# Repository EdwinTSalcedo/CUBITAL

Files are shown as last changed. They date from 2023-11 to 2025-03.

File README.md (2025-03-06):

<h1 align="center">Edge AI-Based Vein Detector for Efficient Venipuncture in the Antecubital Fossa (CUBITAL)</h1> 

This repository contains supplementary material for the conference paper [*"Edge AI-Based Vein Detector for Efficient Venipuncture in the Antecubital Fossa"*](https://link.springer.com/chapter/10.1007/978-3-031-47640-2_24) (MICAI 2023 Oral session). **Authors:** [Edwin Salcedo](https://www.linkedin.com/in/edwinsalcedo) and [Patricia Peñaloza](https://www.linkedin.com/in/patricia-jael-pe%C3%B1aloza-sola-6b9b65131)

[[Project page]](https://edwinsalcedo.com/publication/cubital) [[Dataset]](https://drive.google.com/drive/folders/19DaK7T81qTxgBzirvBGdMyVUj8mOCcOx?usp=sharing) [[arXiv]](https://arxiv.org/pdf/2310.18234) 

<p align="center">

</p>

## Contents
[1. Overview](#overview) </br>
* [Motivation](#motivation) </br>
* [Computer vision system](#cvsystem) </br>
* [Hardware prototype](#hardwareprototype) </br>

[2. Dataset](#dataset) </br>
* [Data collection](#datacollection) </br>
* [Preliminary results](#preliminaryresults) </br>
* [Validation data](#validationdata) </br>

[3. Getting started](#gettingstarted) </br>
* [Initial inference samples](#initialinference) </br>
* [Graphical user interface (GUI)](#gui) </br>
* [On-device deployment](#deployment) </br>

[4. Citation](#citation) </br>
<br>

## 1. Overview

### Motivation
Assessing vein condition and visibility is crucial before obtaining intravenous access in the antecubital fossa, a common site for blood draws and intravenous therapy. However, medical practitioners often struggle with patients who have less visible veins due to factors such as fluid retention, age, obesity, darker skin tones, or diabetes. Current research explores the use of near-infrared (NIR) imaging and deep learning (DL) for forearm vein segmentation, achieving high precision. However, a research gap remains in the recognition of veins, specifically in the antecubital fossa. Additionally, most studies rely on stationary computers, limiting portability for medical personnel during venipuncture procedures. To address these challenges, we propose a portable vein finder for the antecubital fossa based on the Raspberry Pi 4B.

### Computer vision system
We implemented various vein semantic segmentation models in <a href="https://github.com/EdwinTSalcedo/CUBITAL/blob/master/notebooks/Deep_Learning_based_Vein_Segmentation.ipynb
">`Deep_Learning_based_Segmentation.ipynb`</a> and selected the best-performing one—a U-Net model. We then enhanced it in <a href="https://github.com/EdwinTSalcedo/CUBITAL/blob/master/notebooks/Inference_Multi_task_U_Net.ipynb">`Inference_Multi_task_U_Net.ipynb`</a> by adding an additional head to predict the coordinates of the antecubital fossa and its angle. The final computer vision system deployed in the vein finder is shown below:

<p align="center">
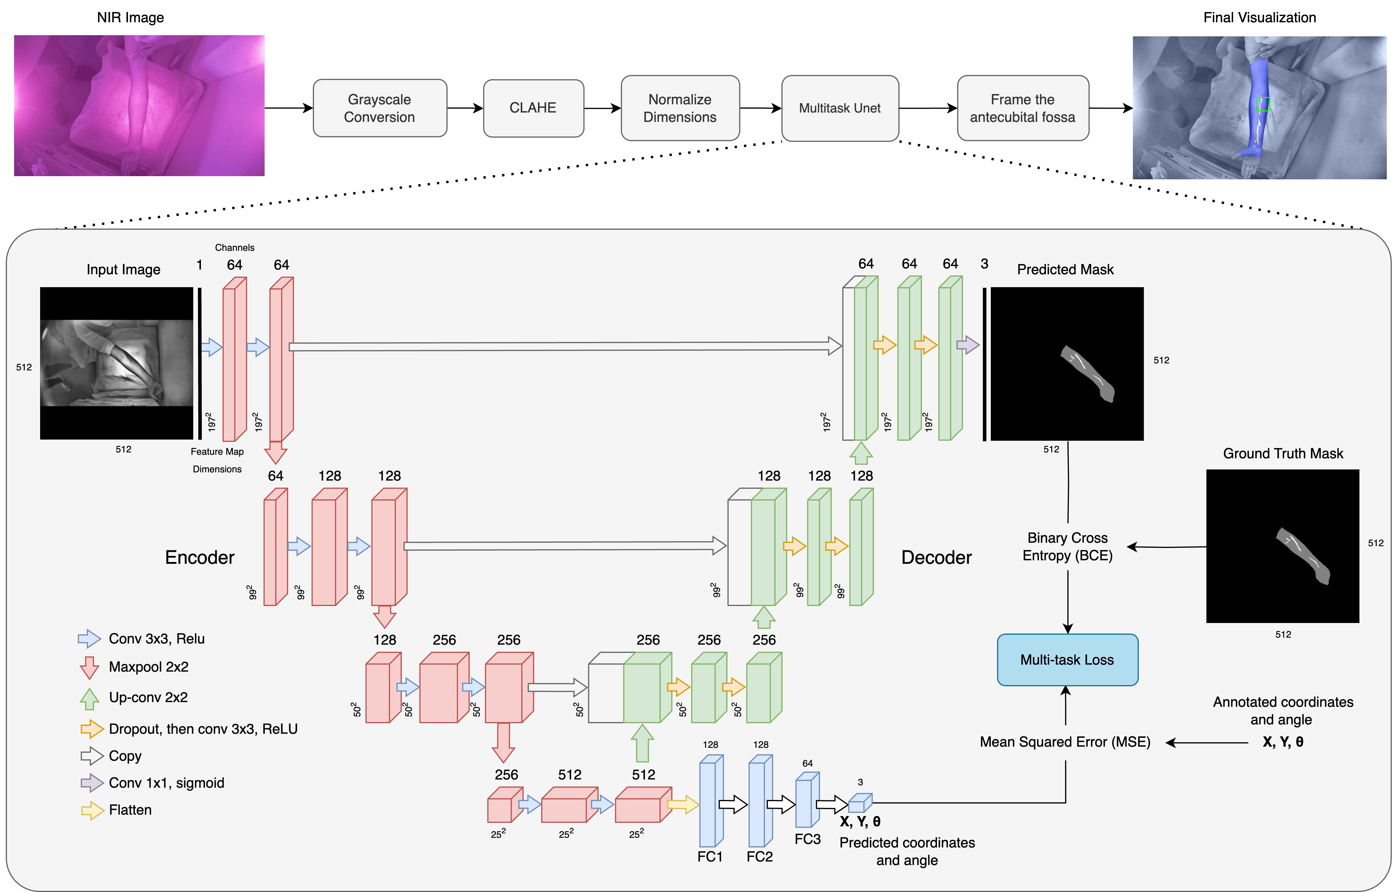
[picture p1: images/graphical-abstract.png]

</p>

We also include plots showing the model's layers in both <a href='https://github.com/EdwinTSalcedo/CUBITAL/blob/master/images/model_plot.png'>horizontal</a> and <a href='https://github.com/EdwinTSalcedo/CUBITAL/blob/master/images/model_plot.jpeg'>vertical</a> alignment.

### Hardware prototype

The device was designed using the 3D CAD software SolidWorks. It can be viewed by opening the file [`Ensamblaje.SLDASM`](cad/Ensamblaje.SLDASM). We also provide a detailed list of its components and visuals of the final 3D-printed prototype.

<p align="center">
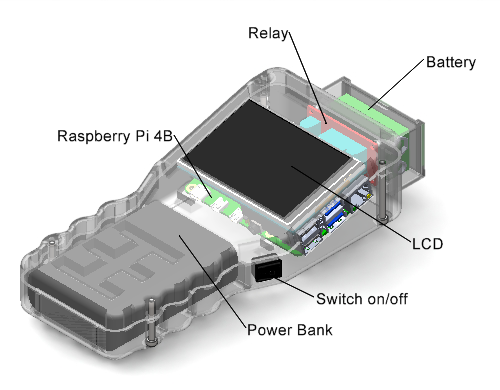
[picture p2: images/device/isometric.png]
  
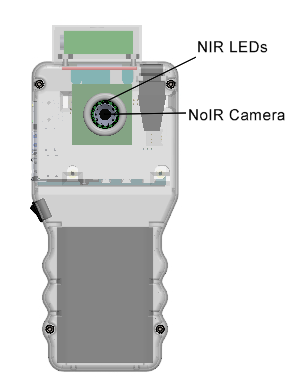
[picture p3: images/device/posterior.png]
  
</p>

| Component | Specifications |  CAD Design |
| --- | --- | --- |
| Power bank | <a href="https://www.amazon.com/Xiaomi-10000mAh-Portable-Charging-Delivery/dp/B08WCKLBJJ" target="_blank"> Xiaomi Mi Power Bank 3 </a> | [`Power bank`](cad/powerbank.SLDPRT) | 
| NIR Camera | <a href="https://www.raspberrypi.com/products/pi-noir-camera-v2/" target="_blank"> Raspberry Pi Camera Module 2 NoIR </a> | [`Holder`](cad/cam_holder.SLDPRT) [`Picam Noir`](cad/pi_cam.SLDPRT) [`Leds Matrix`](cad/leds_matrix.SLDPRT) |  
| LCD display | <a href="https://www.waveshare.com/3.5inch-rpi-lcd-b.htm" target="_blank"> Waveshare 3.5inch Touch Screen </a> | [`Screen`](cad/lcd_screen.SLDPRT) [`LCD Assembly`](cad/rpi_lcd.SLDPRT) |  
| Processing unit | <a href="https://www.raspberrypi.com/products/raspberry-pi-4-model-b/" target="_blank"> Raspberry Pi 4 Model B </a> | [`Raspberry Pi 4B`](cad/raspberryPi4B.SLDPRT) | 
| Relay module | <a href="https://www.amazon.com/Channel-Module-Trigger-Optocoupler-Arduino/dp/B079FJSYGY?th=1" target="_blank"> D.C. 5V 1 Channel Relay Module with Optocoupler </a> | [`Relay`](cad/relay_module.SLDPRT) |
| LED matrix | <a href="https://www.alibaba.com/product-detail/5x7cm-Placa-PCB-perforated_300011363294.html" target="_blank"> Perforated Phenolic Plate 5x7cm </a> + 12 <a href="https://www.amazon.com/Infrared-Lighting-Electronics-Components-Emitting/dp/B01BVGIZGC?th=1" target="_blank"> Infrared Ray IR 940nm Emitter LED Diode Lights </a> | [`LED Matrix`](cad/leds_matrix.SLDPRT) |
| On/off switch | <a href="https://www.amazon.com/KCD1-101-Perforate-19-13-Pin/dp/B0DCP5RSXF?th=1" target="_blank"> ON-OFF Switch 19*13mm KCD1-101 </a> | - |
| Case | - | [`Base`](cad/base.SLDPRT) [`Cover`](cad/cover.SLDPRT) [`Charger`](cad/charger.SLDPRT) |
| 9v battery holder | - | [`Case`](cad/battery_cover.SLDPRT) [`Holder`](cad/battery_holder.SLDPRT) [`Battery`](cad/battery.SLDPRT) | 
 
|  Frontal view |  Back view | Side view | Inner view |  
|---|---|---|---|
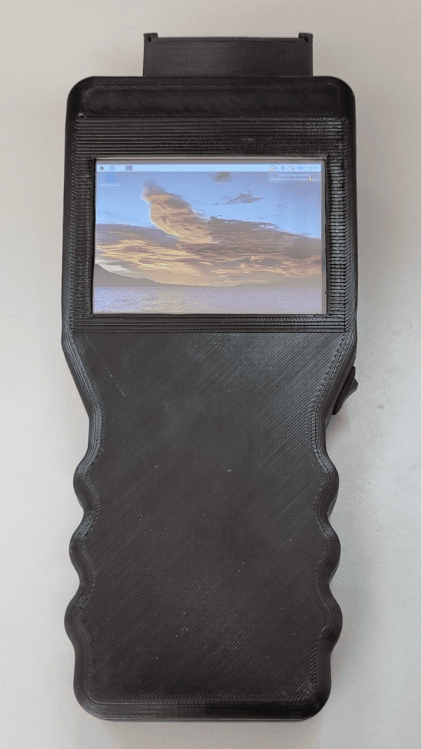
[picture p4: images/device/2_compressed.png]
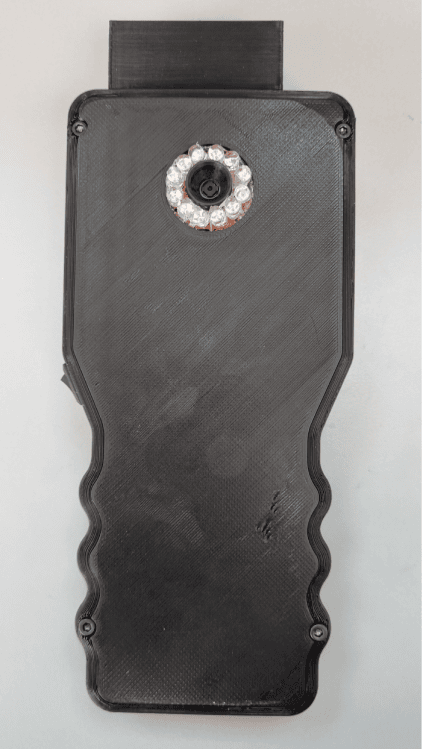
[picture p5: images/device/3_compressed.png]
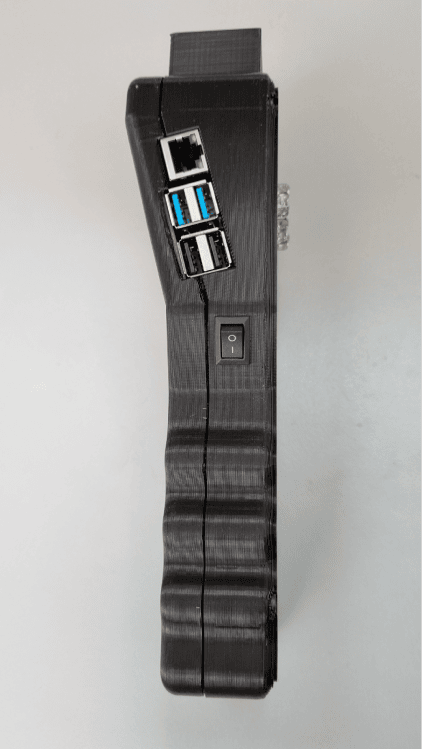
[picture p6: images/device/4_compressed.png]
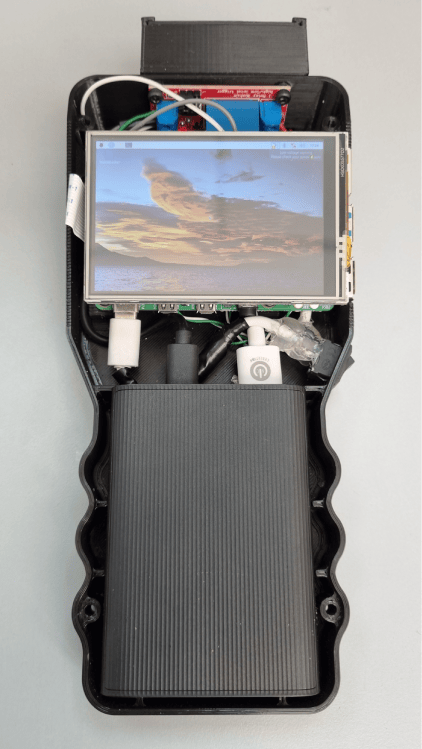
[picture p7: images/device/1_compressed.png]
| |  |  |  |  

## 2. Dataset

### Data collection

To collect the dataset, we captured 2,016 NIR images of 1,008 young individuals with low visibility veins. Each individual placed one arm at a time on a table, allowing us to use a preliminary version of the device to capture an NIR image. The dataset, available [here](https://drive.google.com/drive/folders/19DaK7T81qTxgBzirvBGdMyVUj8mOCcOx?usp=sharing), comes in four versions: 

- **A:** `final_dataset.zip` &rarr; Base version with complete annotations. Three samples are shown below. 
- **B:** `final_augmented_dataset.zip` &rarr; Resulting dataset after applying data augmentation to version A.
- **C:** `square_final_dataset512x512.zip` &rarr; This is a resized version of dataset A, with images reshaped to 512x512 pixels, to match the input requirements of the semantic segmentation models. 
- **D:** `square_augmented_final_dataset512x512.zip` &rarr; Similarly, a resized version of dataset B (512x512).

Below, you can see the original NIR samples, their preprocessed versions (after applying grayscale conversion and CLAHE), and their annotations: a grayscale mask overlay (with a different colormap for visualization), a dot representing the x and y coordinates of the antecubital fossa, and a floating number representing the arm angle. Furthermore, we provide a detailed explanation of the file `final_dataset.zip`, which contains the base version of the dataset.

|  NIR Images |  Preprocessed Images |  Annotations |  
|---|---|---|
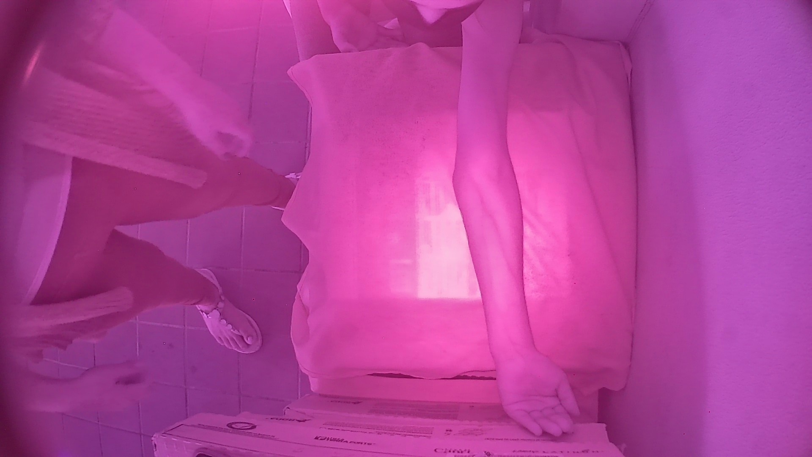
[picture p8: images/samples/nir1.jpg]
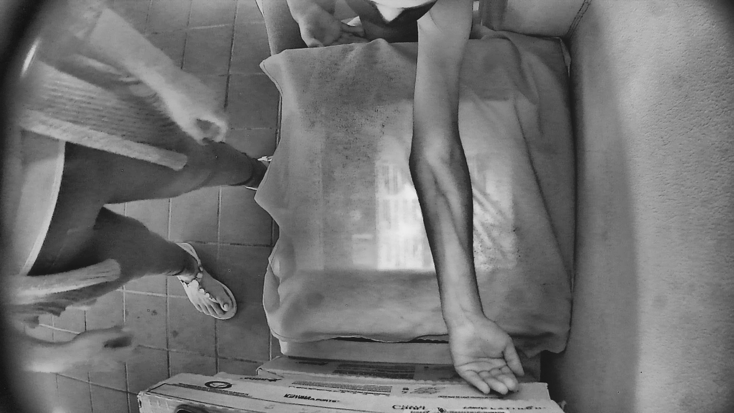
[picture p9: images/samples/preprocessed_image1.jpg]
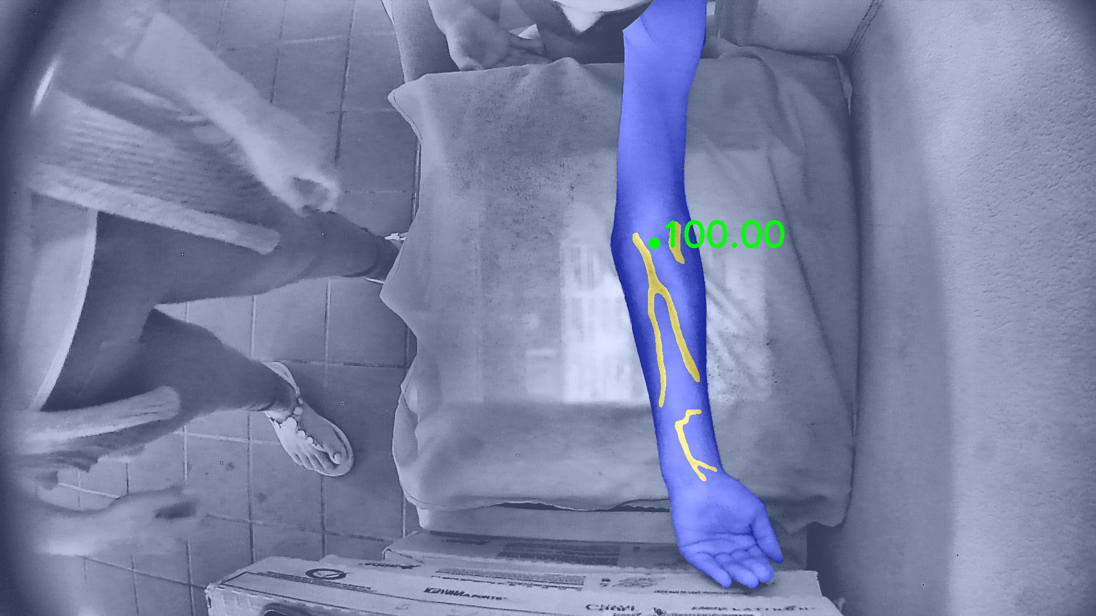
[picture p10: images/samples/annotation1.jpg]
| |  |  |
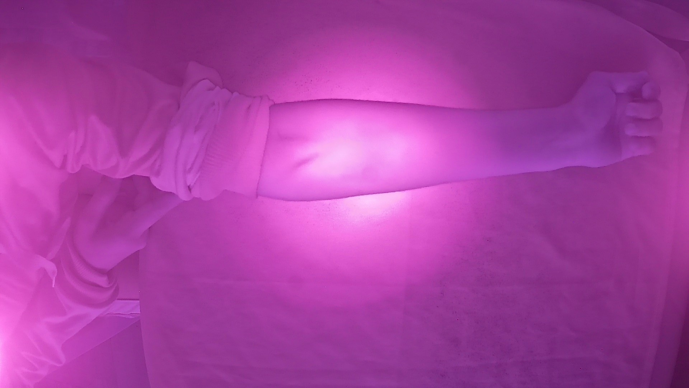
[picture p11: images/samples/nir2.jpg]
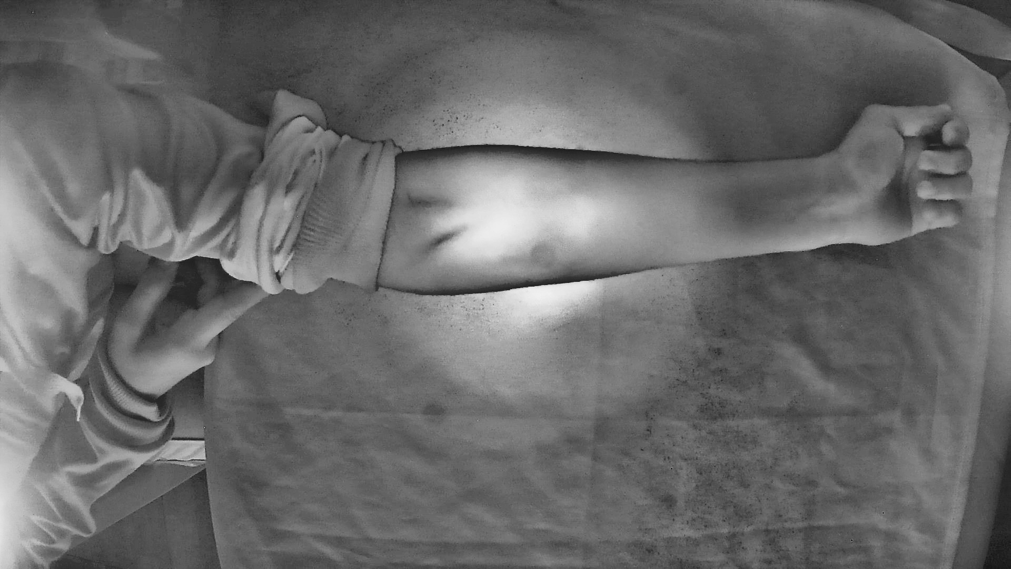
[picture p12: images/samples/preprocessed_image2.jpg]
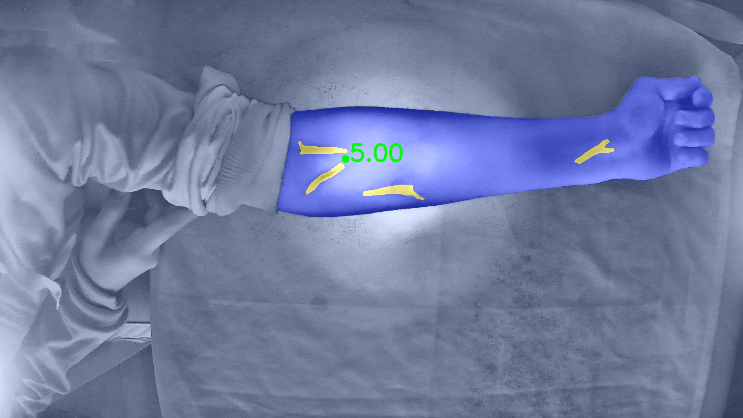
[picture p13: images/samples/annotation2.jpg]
| |  |  |
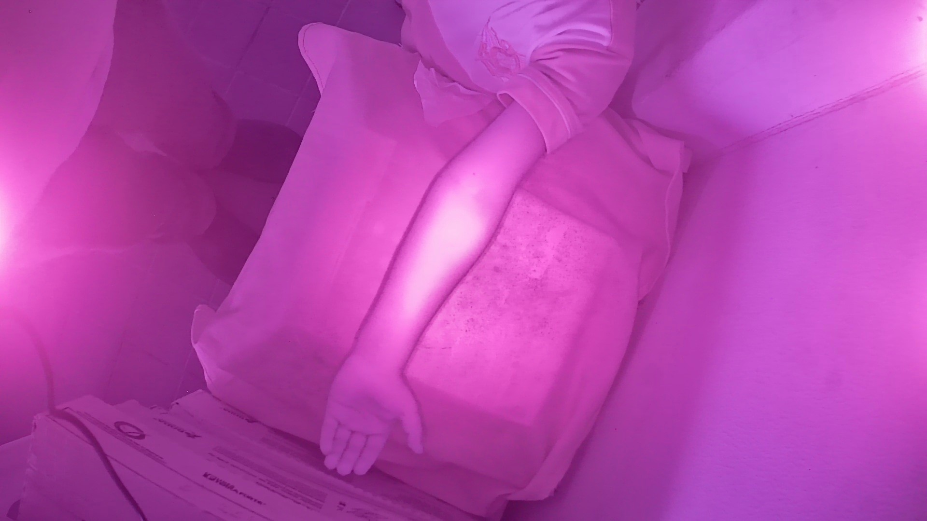
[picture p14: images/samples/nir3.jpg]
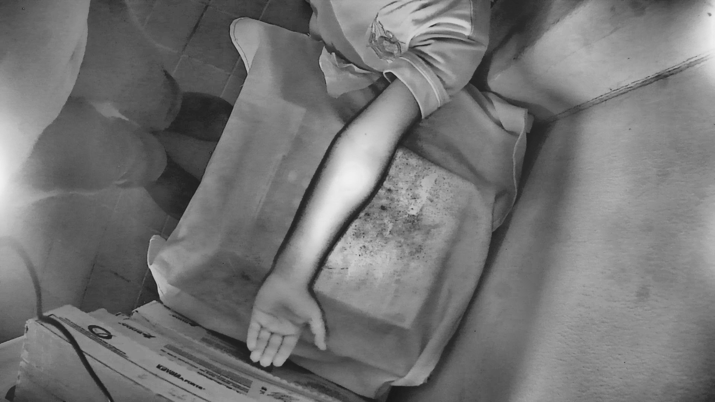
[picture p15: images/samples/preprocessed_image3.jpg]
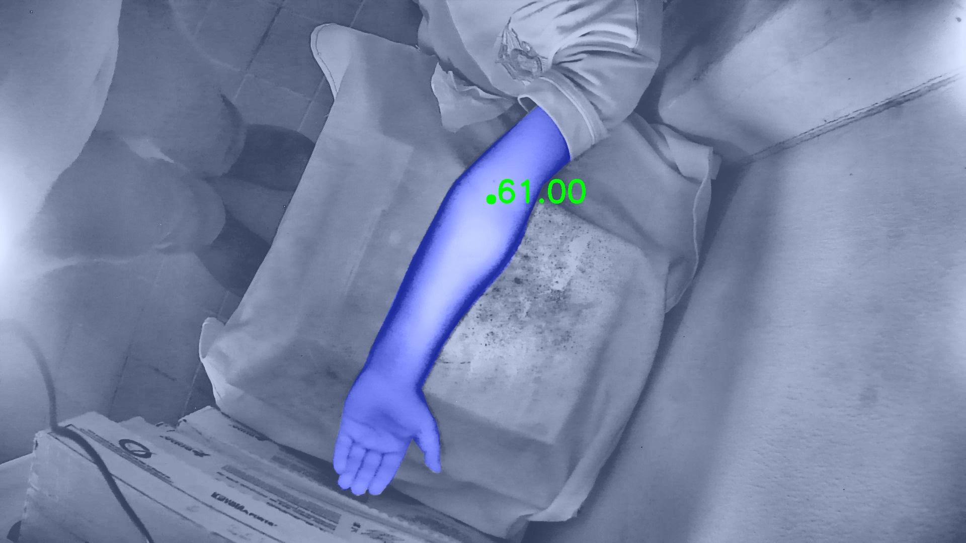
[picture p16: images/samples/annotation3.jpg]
| |  |  | 

``` shell
final_dataset/
------------- dataset.csv # Demographic data for each sample include age, complexion, gender, observations, NIR image location, preprocessed image location, mask location, antecubital fossa coordinates, and arm angle. Each subject contributed two samples, one for each arm.
------------- masks/  # Grayscale images with pixel values 0, 1, and 2, representing the background, arm, and vein, respectively.
------------- nir_images/ # NIR images
------------- preprocessed_images/ # The same NIR images after applying grayscale conversion and CLAHE.
```

### Preliminary results

Initial results from the implementation of U-Net, SegNet, PSPNet, Pix2Pix, and DeepLabv3+ on dataset version C are presented. The results indicate that U-Net achieved the highest accuracy. As a result, we focused our further research on this method for antecubital fossa detection.

<p align="center">
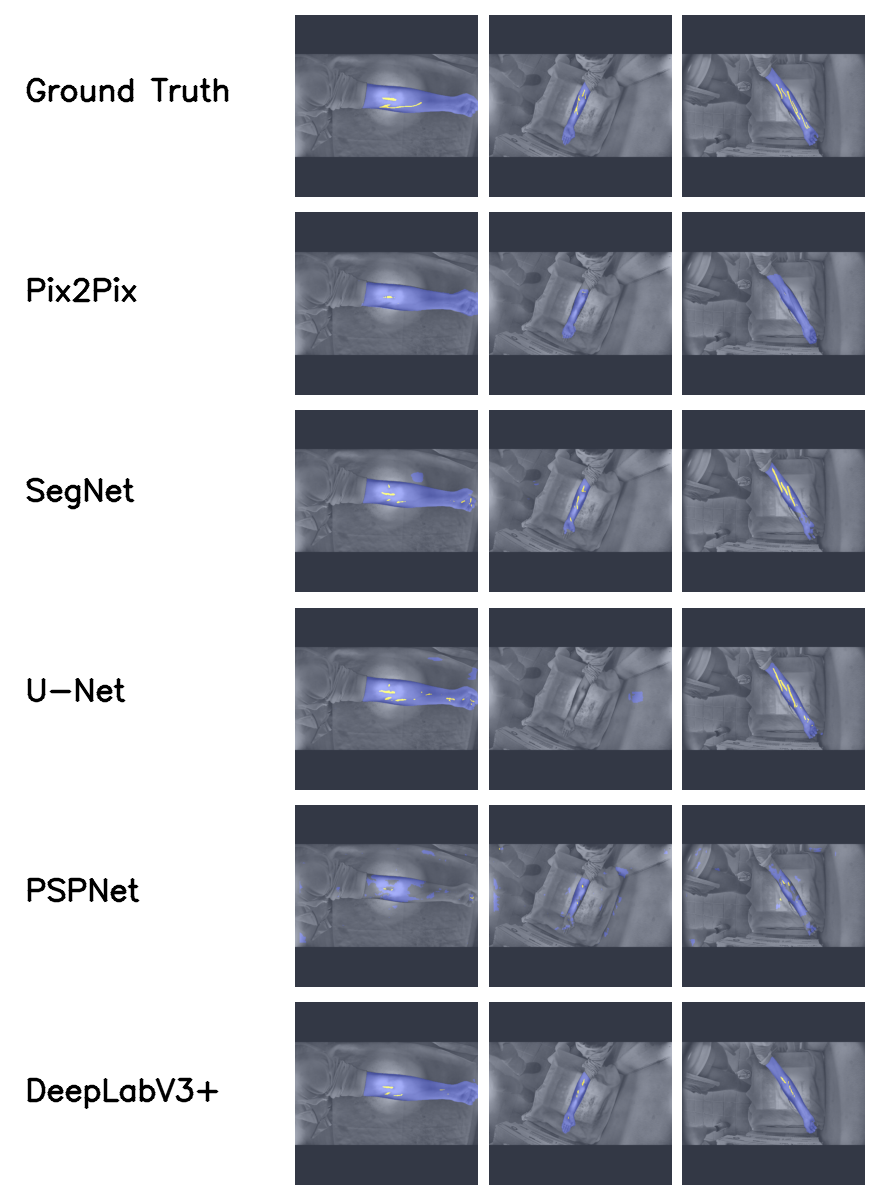
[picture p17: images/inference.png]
  
</p>

### Validation data

To validate the device, we asked three certified nurses to indicate the location where they would perform venipuncture on 384 samples. We saved this information in image format and shared it in the [validation](https://drive.google.com/drive/folders/1itPFfEvblAsP4ZEBzYGGOGrxNw2REc06?usp=sharing) folder, inside the dataset location. We have also included the documents signed by the nurses, confirming their consent to share this information. The annotated images can be used to compare the model's inference to the nurses' chosen venipuncture locations. We used these image subsets to evaluate the proposed base U-Net model's performance, finding an 83% agreement between the regions identified by the nurses and those identified by the [U-Net](https://github.com/EdwinTSalcedo/CUBITAL/blob/master/notebooks/Validation_with_Nurse's_annotations_PyTorch_version.ipynb) vein segmentation algorithm.

## 3. Getting started

### Initial inference samples

First, we provide a pretrained multi-task U-Net model, embedded within a complete pipeline, for performing inference on NIR images included in the folder `subset/preprocessed_images`.  You can run the pipeline by following these steps:

```bash
# Clone the repository
git clone git@github.com:EdwinTSalcedo/CUBITAL.git cubital

# Create and activate a new conda environment
conda create -n new_env python=3.10.12
conda activate new_env

# Install the dependencies 
pip install -r requirements.txt

# Execute inference script
(new_env) python inference.py
```

### Graphical User Interface (GUI)

Furthermore, we provide two GUIs for on-device deployment of the base and modified U-Nets. Run the following command for forearm vein segmentation:

```bash
(new_env) python edgeai/final_interface_vein_segmentation.py 
```
<p align="center">

</p>

And, execute the following command for vein segmentation in the antecubital fossa. This implements the novel architecture proposed in this research. 

```bash
(new_env) python edgeai/final_interface_multitask.py 
```
<p align="center">

</p>
While you can execute any of these scripts with any camera connected to your device, both require an NIR camera and NIR lighting for optimal inference results. 

### On-device deployment

Once the repository is cloned onto a Raspberry Pi 4B, two libraries are required to launch any of the interfaces shown above: OpenCV and TensorFlow Lite. The following steps aim to complete this installation and have been verified on a Raspberry Pi 4B with the latest Raspbian Buster (64-bit) and a 32 GB SD card.

**Step 1:** Install dependencies
1. Updating Existing Packages:
Execute the following command to update and upgrade your system’s packages:

```bash
sudo apt-get update && sudo apt-get upgrade
```
2. Installing Image I/O Packages:
For support with various image file formats, install the necessary packages using:

```bash
sudo apt-get install libjpeg-dev libtiff5-dev libjasper-dev libpng12-dev
```

3. Setting Up Video I/O Packages:
To handle different video file formats and work with video streams, use the commands below:

```bash
sudo apt-get install libavcodec-dev libavformat-dev libswscale-dev libv4l-dev 
sudo apt-get install libxvidcore-dev libx264-dev
```

4. Installing the GTK Development Library:
To compile the highgui module (used for displaying images and creating basic GUIs), install the GTK development library:

```bash
sudo apt-get install libgtk2.0-dev
```

5. Additional Dependencies for OpenCV Optimization:
For enhanced OpenCV operation optimization, install these extra dependencies:

```bash
sudo apt-get install libatlas-base-dev gfortran
```

**Step 2:** Installing pip (Package Management Tool)

If you haven’t installed pip for Python 3 yet, execute the command below:

```bash
sudo apt-get install python3-pip
```

**Step 3:** Installing the Numpy Library:

```bash
pip install numpy
```

**Step 4:** Accessing OpenCV on Raspbian Repository
To locate OpenCV in the default Raspbian Buster repository, use the command:

```bash
apt list python*opencv*
```

**Step 5:** Installing OpenCV
Execute the following command to install OpenCV on Raspberry Pi.

```bash
sudo apt install python3-opencv
```

**Step 6:** Verifying OpenCV Installation
To confirm the installation of OpenCV, use:

```bash
apt show python3-opencv
```

Optionally, you can combine the previous commands into one. The next one worked for us: 

```bash
sudo apt-get install -y libhdf5-dev libc-ares-dev libeigen3-dev gcc gfortran libgfortran5 libatlas3-base libatlas-base-dev libopenblas-dev libopenblas-base libblas-dev liblapack-dev cython3 libatlas-base-dev openmpi-bin libopenmpi-dev python3-dev build-essential cmake pkg-config libjpeg-dev libtiff5-dev libpng-dev libavcodec-dev libavformat-dev libswscale-dev libv4l-dev libxvidcore-dev libx264-dev libfontconfig1-dev libcairo2-dev libgdk-pixbuf2.0-dev libpango1.0-dev libgtk2.0-dev libgtk-3-dev libhdf5-serial-dev libhdf5-103 libqt5gui5 libqt5webkit5 libqt5test5 python3-pyqt5
```

**Step 7:** Run the following command to install TensorFlow Lite's interpreter:

```bash
pip3 install tflite-runtime
```

To check if TensorFlow Lite is installed correctly, run:

```python
python3 -c "import tflite_runtime.interpreter as tflite; print('TensorFlow Lite is installed successfully!')"
```

If no errors appear, the installation was successful. You can run now any of the GUIs shown above!

<p align="center">
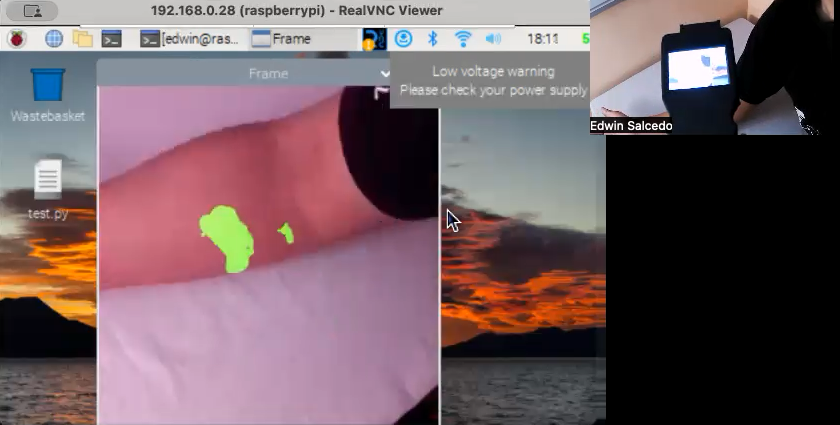
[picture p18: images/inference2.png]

</p>

## 4. Citation

If you find *CUBITAL* useful in your project, please consider citing the following paper:

```
@inproceedings{salcedo2023,
  title={Edge AI-Based Vein Detector for Efficient Venipuncture in the Antecubital Fossa},
  author={Salcedo, Edwin and Pe{\~n}aloza, Patricia},
  booktitle={Mexican International Conference on Artificial Intelligence},
  pages={297--314},
  year={2023},
  organization={Springer}
}
```

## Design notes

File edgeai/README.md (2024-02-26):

# CUBITAL Deployment

## Installation on Raspberry Pi OS

1. Install Raspbian OS Bullseye 64 Bits using the Raspberry Pi Imager: https://www.raspberrypi.com/software/

2. Install the 3.5 inch RPI Display

```bash
$ sudo rm -rf LCD-show
$ git clone https://github.com/goodtft/LCD-show.git
$ chmod -R 755 LCD-show
$ cd LCD-show/
$ sudo ./LCD35-show
```

3. After reboot, change the resolution of the device and activate VNC. 

```bash
$ sudo raspi-config
```

Activate the options: 
- Interface Options -> VNC 
- Display -> Resolution -> 800x600 60Hz 4:3

4. Check the Raspberry OS characteristics

For the OS version:
```bash
$ cat /etc/os-release 
```

This should show: 

```console
PRETTY_NAME="Debian GNU/Linux 11 (bullseye)"
NAME="Debian GNU/Linux"
VERSION_ID="11"
VERSION="11 (bullseye)"
VERSION_CODENAME=bullseye
ID=debian
HOME_URL="https://www.debian.org/"
SUPPORT_URL="https://www.debian.org/support"
BUG_REPORT_URL="https://bugs.debian.org/"
```

For the OS architecture:
```bash
$ uname -a
```

```console
aarch64 GNU/Linux
```

For the Python version:
```bash
$ python -V
```

This should show: 

```
Python 3.9.2
```

5. Update package lists for apt-get

```bash
$ sudo apt-get update
$ sudo apt-get dist-upgrade
```

6. Install some packages

```bash
$ sudo apt-get install -y libhdf5-dev libc-ares-dev libeigen3-dev gcc gfortran libgfortran5 libatlas3-base libatlas-base-dev libopenblas-dev libopenblas-base libblas-dev liblapack-dev cython3 libatlas-base-dev openmpi-bin libopenmpi-dev python3-dev build-essential cmake pkg-config libjpeg-dev libtiff5-dev libpng-dev libavcodec-dev libavformat-dev libswscale-dev libv4l-dev libxvidcore-dev libx264-dev libfontconfig1-dev libcairo2-dev libgdk-pixbuf2.0-dev libpango1.0-dev libgtk2.0-dev libgtk-3-dev libhdf5-serial-dev libhdf5-103 libqt5gui5 libqt5webkit5 libqt5test5 python3-pyqt5
```

7. Clone project and create environment 

```bash
$ git clone git@github.com:EdwinTSalcedo/CUBITAL.git cubital
$ cd cubital
$ sudo pip3 install virtualenv
$ python3 -m venv env
$ source env/bin/activate
```

8. Install the dependencies
```bash
$ pip3 install -R requirements.txt 
```

9. Install TensorFlow Lite Runtime. This is a lighter version of the TF Lite that comes with TensorFlow. Otherwise, we'd need to install the entire framework. See more details [here](https://www.tensorflow.org/lite/guide/python#install_tensorflow_lite_for_python). 

```bash
$ python3 -m pip install tflite-runtime
```

10. Install OpenCV 
```bash
$ pip3 install opencv-python
```

11. Execute the interface
```bash
$ python pyqt_interface.py
```

Alternatively, you can try running the file `picamera_implementation.py`. This contains a similar interface and uses `picamera` to access the camera.  

## Installation on Linux, Windows, MACOS

1. Clone project and create environment 

```bash
$ git clone git@github.com:EdwinTSalcedo/CUBITAL.git cubital
$ cd cubital
$ sudo pip3 install virtualenv
$ python3 -m venv env
$ source env/bin/activate
$ cd edgeai
```

2. Install the dependencies
```bash
$ pip3 install -r requirements.txt 
```

3. Execute the interface
```bash
$ python pyqt_interface.py
```

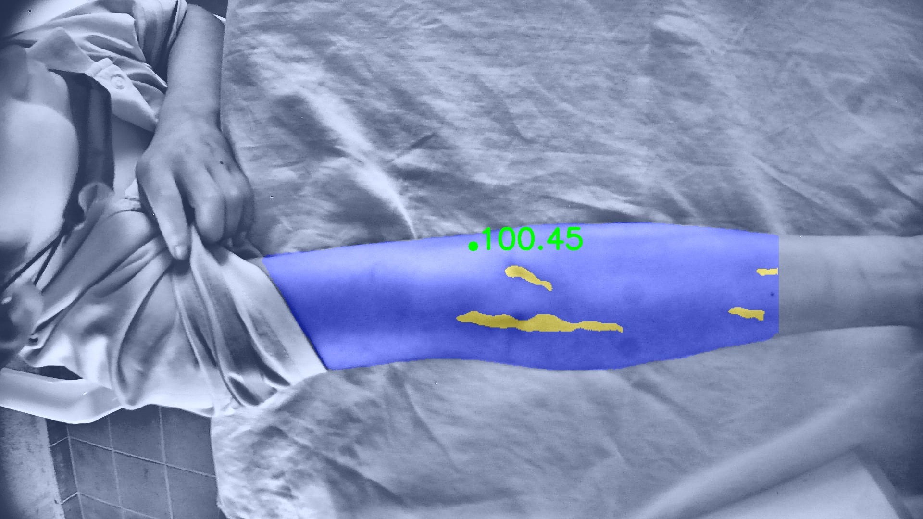
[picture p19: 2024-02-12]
images/inference.jpg

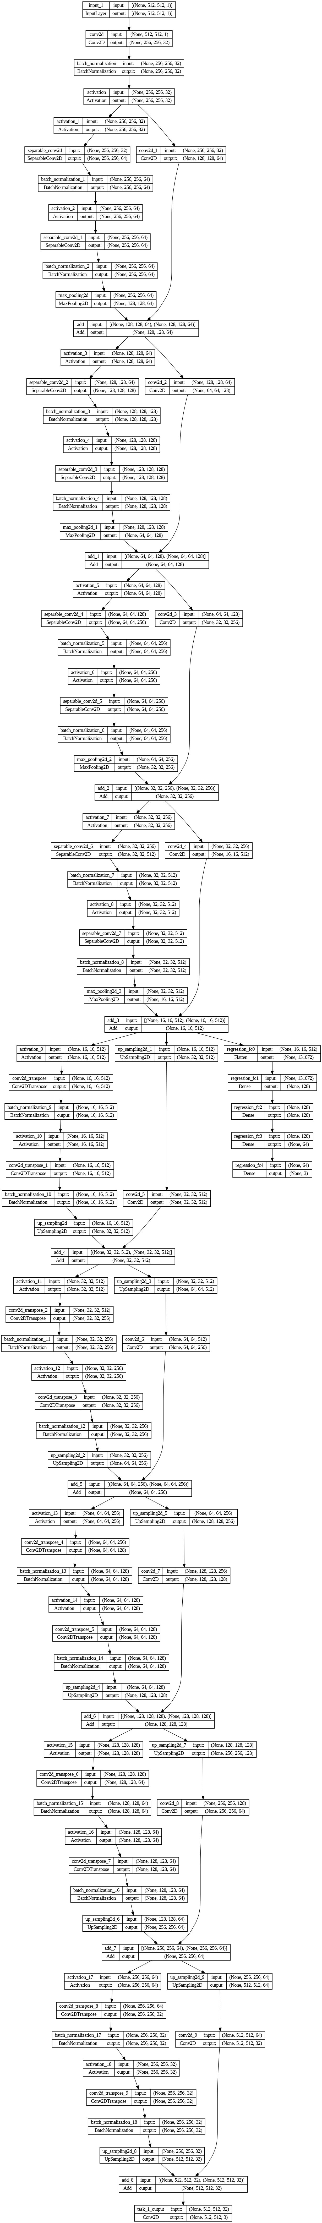
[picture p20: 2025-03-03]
images/model_plot.jpeg

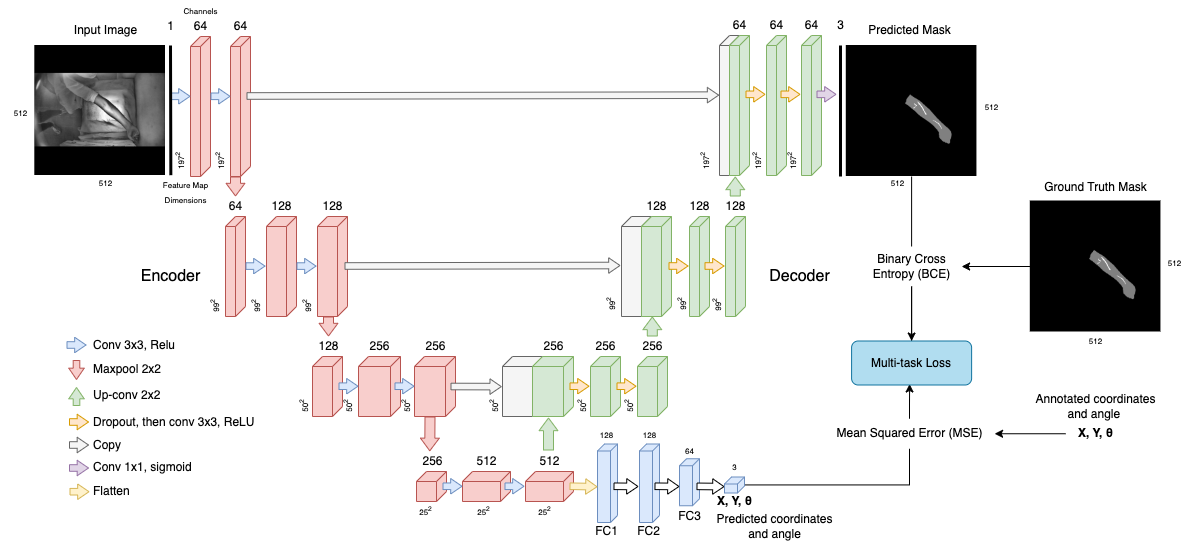
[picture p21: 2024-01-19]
images/final-unet.png

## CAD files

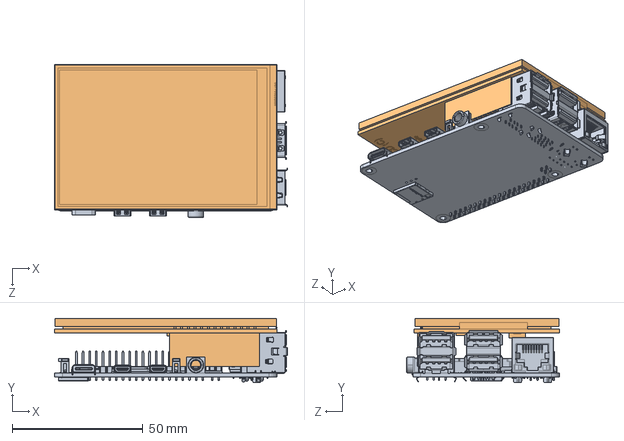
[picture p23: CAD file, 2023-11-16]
cad/RPI_LCD.SLDASM
89.0 x 24.5 x 58.4 mm
raspberryPi4B
lcd_screen

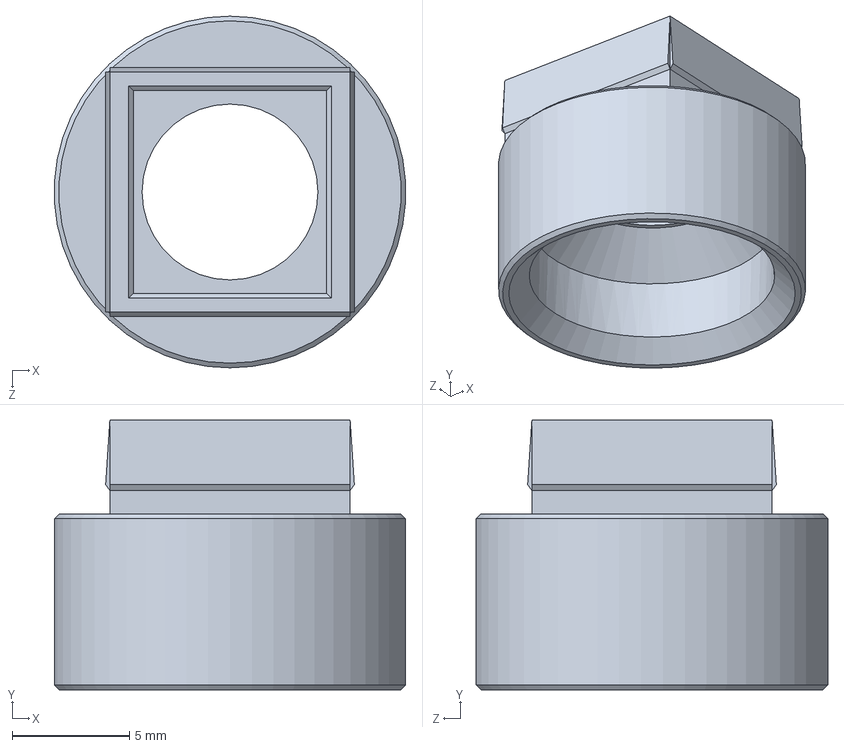
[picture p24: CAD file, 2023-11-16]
cad/cam_holder.SLDPRT
15.0 x 11.5 x 15.0 mm

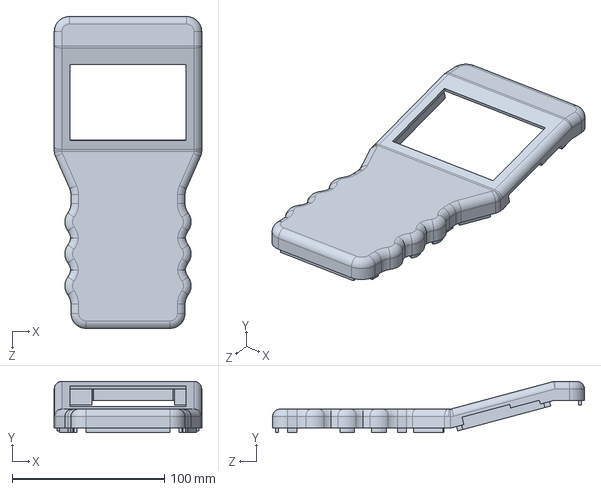
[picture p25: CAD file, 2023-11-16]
cad/cover.SLDPRT
97.0 x 33.7 x 205.0 mm

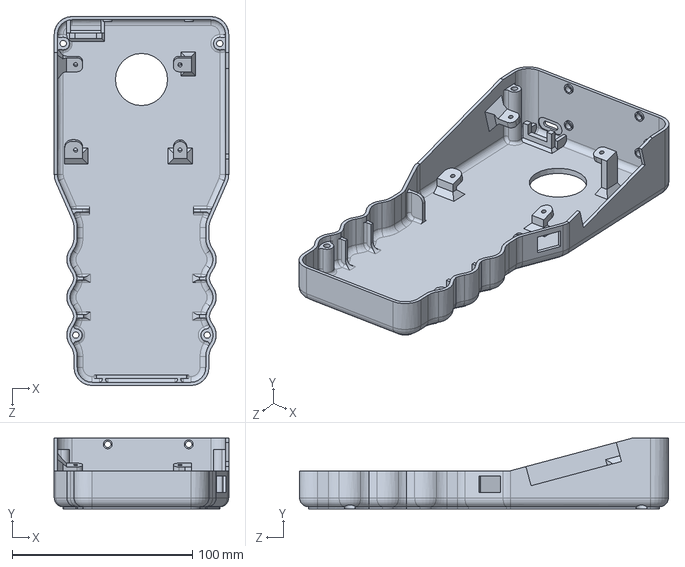
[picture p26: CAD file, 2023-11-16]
cad/base.SLDPRT
97.0 x 39.4 x 205.0 mm

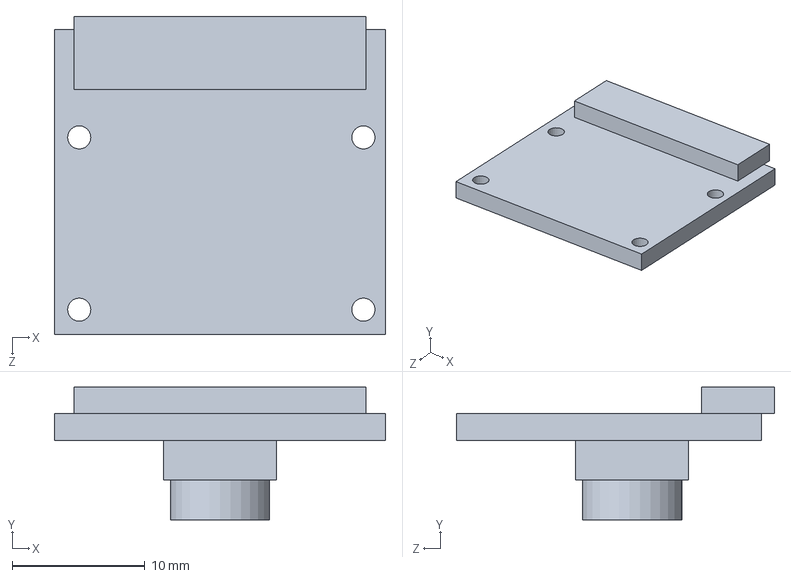
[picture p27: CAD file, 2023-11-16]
cad/pi_cam.SLDPRT
25.0 x 10.0 x 24.0 mm

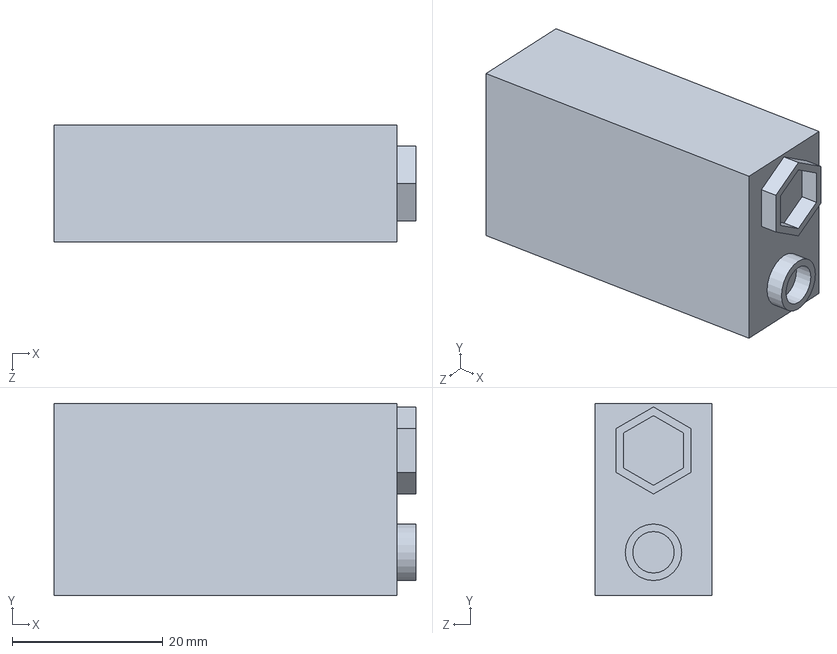
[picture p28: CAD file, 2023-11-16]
cad/battery.SLDPRT
48.0 x 25.5 x 15.5 mm

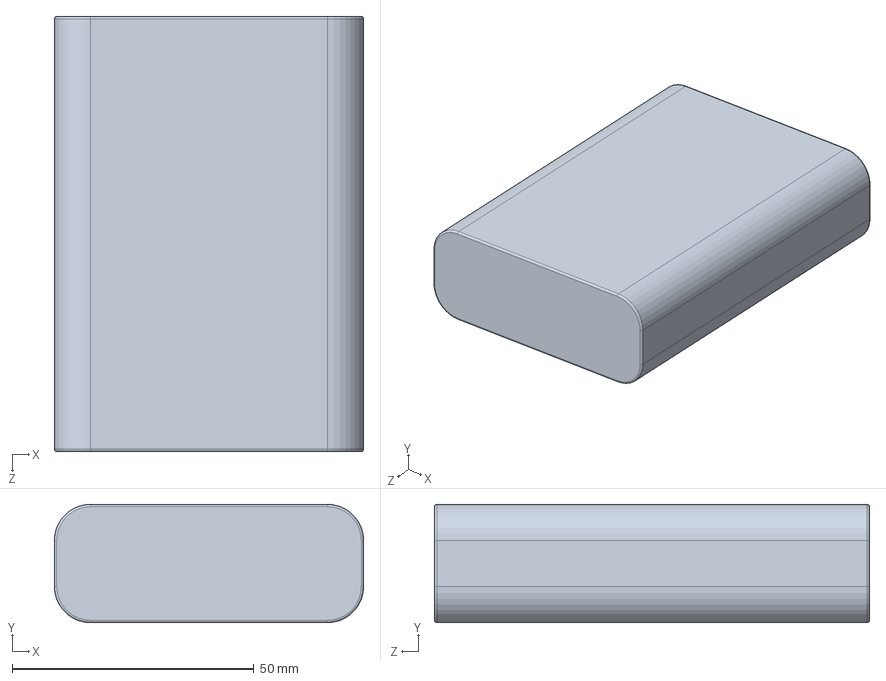
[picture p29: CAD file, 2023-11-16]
cad/powerbank.SLDPRT
64.0 x 24.5 x 90.0 mm

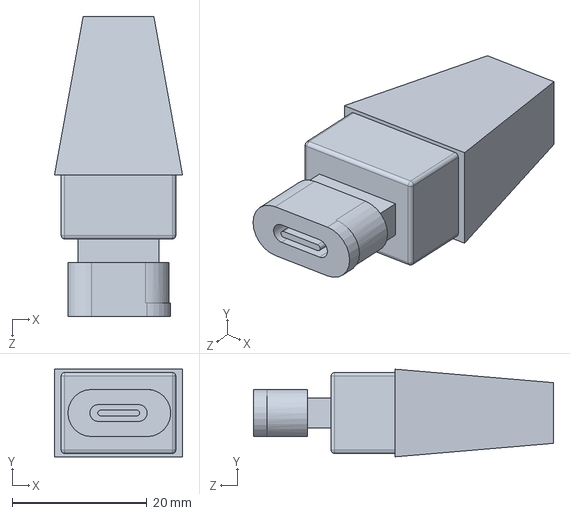
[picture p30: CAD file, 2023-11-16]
cad/charger.SLDPRT
19.0 x 13.0 x 44.5 mm

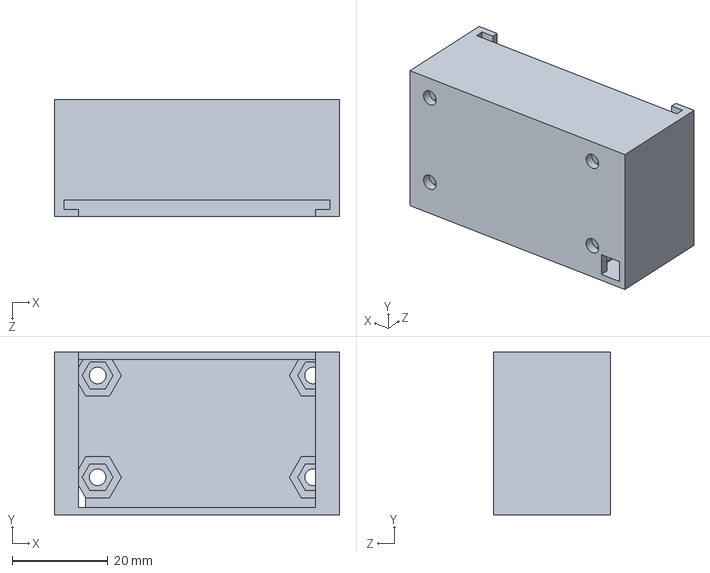
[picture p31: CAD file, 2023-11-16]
cad/battery_holder.SLDPRT
59.5 x 34.0 x 24.5 mm

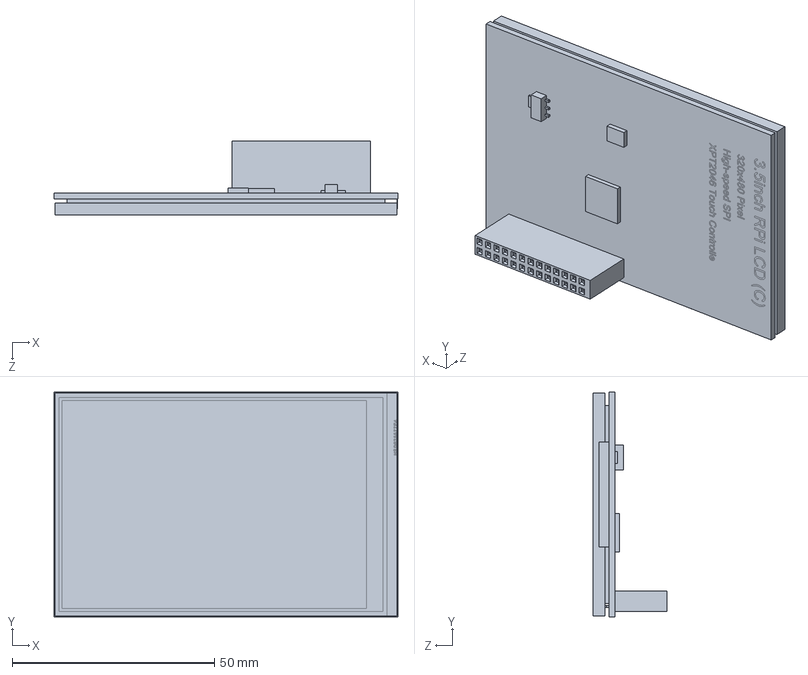
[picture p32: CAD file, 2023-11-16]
cad/lcd_screen.SLDPRT
85.0 x 55.5 x 18.3 mm

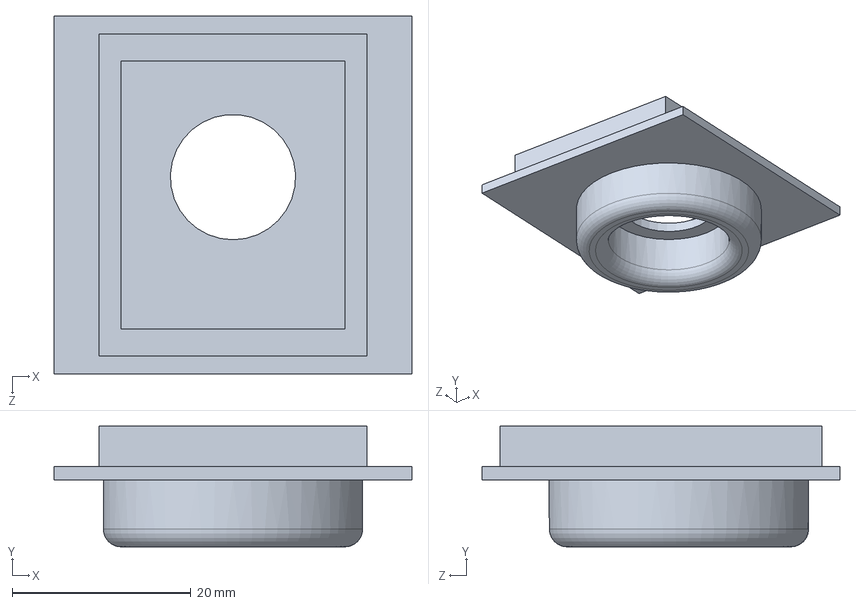
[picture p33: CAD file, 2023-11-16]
cad/leds_matrix.SLDPRT
40.0 x 13.5 x 40.0 mm

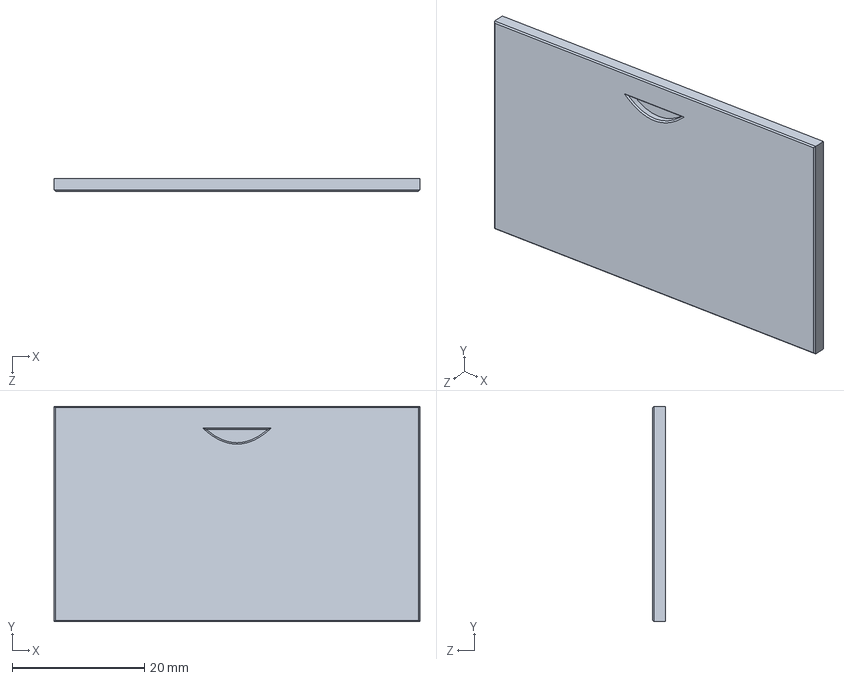
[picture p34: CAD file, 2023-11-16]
cad/battery_cover.SLDPRT
55.2 x 32.5 x 1.90 mm

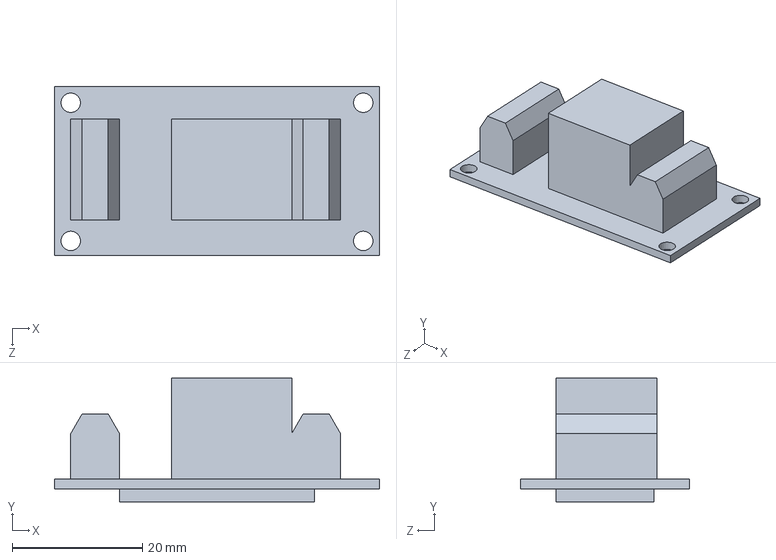
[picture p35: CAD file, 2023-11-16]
cad/relay_module.SLDPRT
50.0 x 19.0 x 26.0 mm

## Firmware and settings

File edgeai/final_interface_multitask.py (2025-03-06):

from PyQt6 import QtCore, QtGui, QtWidgets
from PyQt6.QtCore import *
from PyQt6.QtCore import Qt
from PyQt6.QtGui import *
import cv2
import time
from PIL import ImageQt
import os
import sys
import shutil  
import numpy as np
import tensorflow as tf

INPUT_MODEL_DIMENSION = 512  #Options: 512, 256, 128, 64
HOME = os.getcwd()

unet = tf.saved_model.load(os.path.join(HOME,"edgeai/models/unet_multi"))

# Access the 'serving_default' signature
infer = unet.signatures["serving_default"]

# Define path variables

PICTURES_PATH = os.path.join(HOME, "pictures")

# Check if the folder exists
if os.path.exists(PICTURES_PATH):
    shutil.rmtree(PICTURES_PATH)
os.mkdir(PICTURES_PATH)

class UI_MainWindow():
    def setupUI(self, main_window):
        self.camera_on = False
        self.picture_pixmaps = {}

        # Set main window
        main_window.setWindowTitle("CUBITAL")
        main_window.setObjectName("main_window")
        main_window.resize(670, 370)
        self.central_widget = QtWidgets.QWidget(main_window)
        self.central_widget.setObjectName("central_widget")

        # Set video pane
        self.label = QtWidgets.QLabel(self.central_widget)
        self.label.setGeometry(QtCore.QRect(10, 10, 480, 320))
        self.label.setObjectName("label")

        # Set buttons for start/stop capturing video stream 
        self.start_stream_button = QtWidgets.QPushButton(self.central_widget)
        self.start_stream_button.setGeometry(QtCore.QRect(500, 263, 80, 70))
        self.start_stream_button.setObjectName("start_stream_button")
        self.start_stream_button.clicked.connect(self.start_video)
        self.start_stream_button.setText("START")
        
        # Set buttons for capturing pictures
        self.take_picture_button = QtWidgets.QPushButton(self.central_widget)
        self.take_picture_button.setGeometry(QtCore.QRect(582, 263, 80, 70))
        self.take_picture_button.setObjectName("take_picture_button")
        self.take_picture_button.clicked.connect(self.save_picture)
        self.take_picture_button.setText("CAPTURE")
        
        # Set buttons for selecting pictures on the right
        self.picture1_button = QtWidgets.QPushButton(self.central_widget)
        self.picture1_button.setGeometry(QtCore.QRect(500, 3, 165, 124))
        self.picture1_button.setText("")
        self.picture1_button.setObjectName("picture1_button")
        self.picture1_button.clicked.connect(self.visualize_picture1)
        self.picture2_button = QtWidgets.QPushButton(self.central_widget)
        self.picture2_button.setGeometry(QtCore.QRect(500, 129, 165, 124))
        self.picture2_button.setText("")
        self.picture2_button.setObjectName("picture2_button")
        self.picture2_button.clicked.connect(self.visualize_picture2)

        # Set labels to ask to press the buttons again
        self.label_first_picture = QtWidgets.QLabel(self.central_widget)
        self.label_first_picture.setGeometry(QtCore.QRect(500, 97, 165, 25))
        self.label_first_picture.setObjectName("label_first_picture")
        self.label_first_picture.setText("Press again")
        self.label_first_picture.setAlignment(Qt.AlignmentFlag.AlignCenter)
        self.label_first_picture.setVisible(False)
        self.label_first_picture.setStyleSheet("background-color: black;color:white;opacity: 0.7;") 
        self.label_second_picture = QtWidgets.QLabel(self.central_widget)
        self.label_second_picture.setGeometry(QtCore.QRect(500, 225, 165, 25))
        self.label_second_picture.setObjectName("label_second_picture")
        self.label_second_picture.setText("Press again")
        self.label_second_picture.setAlignment(Qt.AlignmentFlag.AlignCenter)
        self.label_second_picture.setVisible(False)
        self.label_second_picture.setStyleSheet("background-color: black;color:white;opacity: 0.7;") 

        # Finish configuring the main window 
        main_window.setCentralWidget(self.central_widget)
        self.menubar = QtWidgets.QMenuBar(main_window)
        self.menubar.setGeometry(QtCore.QRect(0, 0, 670, 21))
        self.menubar.setObjectName("menubar")
        main_window.setMenuBar(self.menubar)
        self.statusbar = QtWidgets.QStatusBar(main_window)
        self.statusbar.setObjectName("statusbar")
        main_window.setStatusBar(self.statusbar)
        QtCore.QMetaObject.connectSlotsByName(main_window)

    def start_video(self):
        if self.camera_on:
            self.Work.stop()
            self.camera_on = False
            self.start_stream_button.setText("START")
            self.take_picture_button.setEnabled(False)
        else:
            if not self.label.isVisible():
                self.label.setVisible(True)
            self.Work = Work()
            self.Work.start()
            self.Work.imageupd.connect(self.set_video_stream)
            self.camera_on = True
            self.start_stream_button.setText("STOP")
            self.take_picture_button.setEnabled(True)

    def set_video_stream(self, stream):
        self.label.setPixmap(QPixmap.fromImage(stream))

    def save_picture(self):
        # Obtain image from the camera (in Qpixmap format) and convert it to a Pillow image
        pixmap_image = self.label.pixmap()
        pillow_image = ImageQt.fromqpixmap(pixmap_image)
        
        # Save picture
        self.filename = 'picture' + str(time.strftime("%Y%m%d%H%M%S")) + '.png'
        pillow_image.save(os.path.join(PICTURES_PATH, self.filename))
        
        if "first" in self.picture_pixmaps: 
            self.picture_pixmaps["second"] = self.picture_pixmaps["first"]
            previous_pixmap = self.picture_pixmaps["first"]
            self.picture2_button.setIcon(QIcon(previous_pixmap))
            self.picture2_button.setIconSize(self.picture2_button.size())

        # Display the latest image on the first button
        self.picture_pixmaps["first"] = pixmap_image
        self.picture1_button.setIcon(QIcon(pixmap_image))
        self.picture1_button.setIconSize(self.picture1_button.size())
          
    def visualize_picture1(self):
        if self.camera_on:
            self.Work.stop()
            self.label.clear()
            self.camera_on = False
            self.start_stream_button.setText("START")
            self.take_picture_button.setEnabled(False)
            self.label.setVisible(False)
            self.label_first_picture.setVisible(True)
        else: 
            self.label.setPixmap(self.picture_pixmaps["first"])
            self.label.setVisible(True)
            self.label_first_picture.setVisible(False)

    def visualize_picture2(self):
        if self.camera_on:
            self.Work.stop()
            self.label.clear()
            self.camera_on = False
            self.start_stream_button.setText("START")
            self.take_picture_button.setEnabled(False)
            self.label.setVisible(False)
            self.label_second_picture.setVisible(True)
        else:
            self.label.setPixmap(self.picture_pixmaps["second"])
            self.label.setVisible(True)
            self.label_second_picture.setVisible(False)

class Work(QThread):
    '''
        This class lets process each input frame in a different thread. Then, it applies a model 
        to obtain the segments representing the vein in the antecubital fossa. 
    '''
    imageupd = pyqtSignal(QImage)

    def run(self):
        self.running_thread = True
        cap = cv2.VideoCapture(0)

        # Dimensions of the image to be displayed in the interface, considering the 16:9 aspect ratio. 
        IMAGE_WIDTH_TO_SHOW = 568
        IMAGE_HEIGHT_TO_SHOW = 320
        
        # Piles to average the x and y coordinates of the antecubital fossa localised by the model.
        x_buffer = []
        y_buffer = []
        buffer_size = 30

        masks_buffer = []
        masks_buffer_size = 10

        while self.running_thread:
            ret, frame = cap.read()

            if ret:
                image = cv2.cvtColor(frame, cv2.COLOR_BGR2RGB)
                image = cv2.flip(image, 1)
                image = cv2.resize(image, (IMAGE_WIDTH_TO_SHOW, IMAGE_HEIGHT_TO_SHOW), interpolation = cv2.INTER_AREA)
                
                # Obtain the predicted mask
                left_limit = int(IMAGE_HEIGHT_TO_SHOW//2)
                right_limit = left_limit + IMAGE_HEIGHT_TO_SHOW
                new_image_to_segment = image[:,left_limit:right_limit,:]
                new_image_to_segment = cv2.resize(new_image_to_segment, (INPUT_MODEL_DIMENSION, INPUT_MODEL_DIMENSION), interpolation = cv2.INTER_AREA)
                mask, values = self.segment_and_predict(new_image_to_segment)

                mask[mask == 1] = 0
                mask[mask == 2] = 255

                # Average the present and previous masks in a weighted manner
                if len(masks_buffer) >= masks_buffer_size: 
                    masks_buffer.pop(0)
                masks_buffer.append(mask)
                new_mask = (np.where(self.average(masks_buffer)>0.5, 255, 0)).astype(np.uint8)

                resized_mask = cv2.resize(new_mask, (IMAGE_HEIGHT_TO_SHOW, IMAGE_HEIGHT_TO_SHOW), interpolation = cv2.INTER_AREA)
                _, binary_mask = cv2.threshold(resized_mask, 127, 255, cv2.THRESH_BINARY)

                masked_mask = np.zeros((image.shape[0],image.shape[1]), dtype=np.uint8)
                masked_mask[:,left_limit:right_limit] = binary_mask

                # Include a bounding box by using the x and y coordinates of the antecubital fossa obtained by the model.
                x = int(values[0][0] * IMAGE_HEIGHT_TO_SHOW) + (left_limit)
                y = int(values[0][1] * IMAGE_HEIGHT_TO_SHOW)
                angle = values[0][2] * 180

                if len(x_buffer) >= buffer_size:
                    x_buffer.pop(0)
                x_buffer.append(x)

                if len(y_buffer) > buffer_size:
                    y_buffer.pop(0)
                y_buffer.append(y)

                # Average the x and y coordinates to avoid inconstant coordinates
                new_x = int(sum(x_buffer) / len(x_buffer) if x_buffer else 0)
                new_y = int(sum(y_buffer) / len(y_buffer) if y_buffer else 0)

                # Remove segments out of the antecubital fossa's window 
                window_size = 100
                window_size = window_size // 2

                bbox_x1 = new_x-window_size
                bbox_x2 = new_x+window_size
                bbox_y1 = new_y-window_size
                bbox_y2 = new_y+window_size
                
                masked_mask[:bbox_y1,:masked_mask.shape[1]] = 0
                masked_mask[bbox_y1:bbox_y2,:bbox_x1] = 0
                masked_mask[bbox_y1:bbox_y2,bbox_x2:] = 0
                masked_mask[bbox_y2:,:masked_mask.shape[1]] = 0

                # Change the color of all vein segments to green
                output = cv2.cvtColor(masked_mask, cv2.COLOR_GRAY2RGB)
                output[masked_mask==255] = [0,255,0]                
                combined = cv2.addWeighted(output, 1, image, 0.8, 0)

                # Draw the bounding box representing the antecubital fossa
                cv2.rectangle(combined,(bbox_x1,bbox_y1),(bbox_x2,bbox_y2),(31,255,255),1)

                qimage = QImage(combined.data, combined.shape[1], combined.shape[0], QImage.Format.Format_RGB888)
                self.imageupd.emit(qimage)

        cap.release()

    def stop(self):
        self.running_thread = False
        self.quit()

    def average(self, arrays):
        assert len(arrays) > 0, "Input list must not be empty"
        assert all(arr.shape == arrays[0].shape for arr in arrays), "All arrays must have the same shape"

        avg = np.mean(arrays, axis=0)
        return avg

    def segment_and_predict(self, image):
       image = cv2.cvtColor(image, cv2.COLOR_RGB2GRAY)  

       # Implement CLAHE and normalise the image
       clahe = cv2.createCLAHE(clipLimit=2.0, tileGridSize=(8,8))
       image = clahe.apply(image)
       image = image.astype(dtype=np.float32) / 127.5 - 1

       # Convert image to TensorFlow tensor
       image = np.expand_dims(np.expand_dims((image), axis=0), axis=3)
       image_tensor = tf.convert_to_tensor(image, dtype=tf.float32)

       # Obtain inference results with the model
       results = infer(image_tensor)
       values = results['output_1']
       mask = results['output_0']
       mask = np.squeeze(mask)
       prediction_mask = np.argmax(mask, axis=2).astype(np.uint8)

       return prediction_mask, values
        
if __name__ == "__main__":
    app = QtWidgets.QApplication(sys.argv)
    main_window = QtWidgets.QMainWindow()
    ui = UI_MainWindow()
    ui.setupUI(main_window)
    main_window.show()
    sys.exit(app.exec())

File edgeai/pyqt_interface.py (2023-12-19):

# -*- coding: utf-8 -*-
from PyQt5 import QtCore, QtGui, QtWidgets
from PyQt5.QtCore import *
from PyQt5.QtGui import *
import cv2
import time
from PIL import ImageQt, Image, ImageTk
import sys
import tflite_runtime.interpreter as tflite
import numpy as np

INPUT_MODEL_DIMENSION = 128  #Options: 512, 256, 128, 64

# Load the TFLite model and allocate tensors. Note this load the corresponding model given the input dimensions. 
interpreter = tflite.Interpreter(model_path=f"models/unet{INPUT_MODEL_DIMENSION}x{INPUT_MODEL_DIMENSION}.tflite")
# Assign memory addresses to save new data in tensor format
interpreter.allocate_tensors()

# Get input and output tensors
input_details = interpreter.get_input_details()
output_details = interpreter.get_output_details()

class Ui_MainWindow(object):
    def setupUi(self, MainWindow):
        MainWindow.setObjectName("CUBITAL")
        MainWindow.resize(480, 275)
        self.centralwidget = QtWidgets.QWidget(MainWindow)
        self.centralwidget.setObjectName("centralwidget")
        self.widget = QtWidgets.QWidget(self.centralwidget)
        self.widget.setGeometry(QtCore.QRect(2, 9, 475, 250))
        self.widget.setObjectName("widget")
        self.gridLayout = QtWidgets.QGridLayout(self.widget)
        self.gridLayout.setContentsMargins(0, 0, 0, 0)
        self.gridLayout.setObjectName("gridLayout")
        self.label = QtWidgets.QLabel(self.widget)
        self.label.setMinimumSize(QtCore.QSize(480, 320))
        self.label.setMaximumSize(QtCore.QSize(480, 320))
        self.label.setStyleSheet("background-color:rgb(255, 255, 255);")
        self.label.setText("")
        self.label.setObjectName("label")
        self.gridLayout.addWidget(self.label, 0, 0, 1, 1)
        self.verticalLayout = QtWidgets.QVBoxLayout()
        self.verticalLayout.setObjectName("verticalLayout")
        self.label_2 = QtWidgets.QLabel(self.widget)
        self.label_2.setMinimumSize(QtCore.QSize(165, 124))
        self.label_2.setMaximumSize(QtCore.QSize(165, 124))
        self.label_2.setText("")
        self.label_2.setAlignment(QtCore.Qt.AlignCenter)
        self.label_2.setObjectName("label_2")
        self.verticalLayout.addWidget(self.label_2)
        self.label_3 = QtWidgets.QLabel(self.widget)
        self.label_3.setMinimumSize(QtCore.QSize(165, 124))
        self.label_3.setMaximumSize(QtCore.QSize(165, 124))
        self.label_3.setText("")
        self.label_3.setObjectName("label_3")
        self.verticalLayout.addWidget(self.label_3)
        self.horizontalLayout = QtWidgets.QHBoxLayout()
        self.horizontalLayout.setObjectName("horizontalLayout")
        self.pushButton = QtWidgets.QPushButton(self.widget)
        self.pushButton.setMinimumSize(QtCore.QSize(80, 70))
        self.pushButton.setMaximumSize(QtCore.QSize(80, 70))
        self.pushButton.setObjectName("pushButton")
        self.pushButton.setCursor(QtGui.QCursor(QtCore.Qt.PointingHandCursor))
        self.verticalLayout.addLayout(self.horizontalLayout)
        self.gridLayout.addLayout(self.verticalLayout, 0, 1, 1, 1)
        MainWindow.setCentralWidget(self.centralwidget)
        self.menubar = QtWidgets.QMenuBar(MainWindow)
        self.menubar.setGeometry(QtCore.QRect(0, 0, 670, 21))
        self.menubar.setObjectName("menubar")
        MainWindow.setMenuBar(self.menubar)
        self.statusbar = QtWidgets.QStatusBar(MainWindow)
        self.statusbar.setObjectName("statusbar")
        MainWindow.setStatusBar(self.statusbar)

        self.camera_on = False
        self.image_list = []
        self.pushButton.clicked.connect(self.start_video)
        self.retranslateUi(MainWindow)
        QtCore.QMetaObject.connectSlotsByName(MainWindow)

    def start_video(self):
        if not self.camera_on:
            self.Work = Work()
            self.Work.start()
            self.Work.Imageupd.connect(self.Imageupd_slot)
            self.camera_on = True
            self.pushButton.setText("STOP")

        else:
            self.Work.stop()
            self.camera_on = False
            self.pushButton.setText("START")

    def Imageupd_slot(self, Image):
        self.label.setPixmap(QPixmap.fromImage(Image))

    def savePhoto(self):
        gallery = ImageQt.fromqpixmap(self.label.pixmap())
        self.filename = 'Snapshot ' + str(time.strftime("%Y-%b-%d at %H.%M.%S %p")) + '.png'
        gallery.save(self.filename)

        pixmap = QPixmap(self.filename)
        self.image_list.append(pixmap)
        scaled_pixmap = pixmap.scaled(self.label_2.width(), self.label_2.height())
        self.label_2.setPixmap(scaled_pixmap)

        if len(self.image_list)>=2:
            scaled_pixmap = self.image_list[-2].scaled(self.label_3.width(), self.label_3.height())
            self.label_3.setPixmap((scaled_pixmap))

    def retranslateUi(self, MainWindow):

        _translate = QtCore.QCoreApplication.translate
        MainWindow.setWindowTitle(_translate("CUBITAL", "CUBITAL"))
        self.pushButton.setText(_translate("START", "START"))
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

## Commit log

2024-02-12 Added samples with annotations
2025-02-12 Added pictures of the device
